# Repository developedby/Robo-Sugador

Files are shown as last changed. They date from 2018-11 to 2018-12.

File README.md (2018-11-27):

# robo-sugador

robo que suga bolinhas de tenis de mesa
Desenvolvido para a disciplina Oficina de Integração 2 - Engenharia de Computação UTFPR-CT - 2018.2

## Autores
* Nicolas Abril
* Álefe Felipe Gonçalves Pereira Dias
* Lucca Rawlyk

## Programas necessários
* O código do robo é feito em python 3 para Raspberry Pi rodando Raspbian
* Os diagramas do HW são em Eagle 9
* Os diagramas do SW são em StarUML
* Os modelos mecânicos e os arquivos para impressão 3D são feitos em SketchUp
* Os diagramas de sistema foram feitos no draw.io
* O aplicativo foi feito com Android Studio

## Bibliotecas necessárias
* RPi.GPIO
* gpiozero
* bluetooth
* bluez (para python3 necessário instalar por pip)
* opencv (talvez seja necessário instalar por pip)

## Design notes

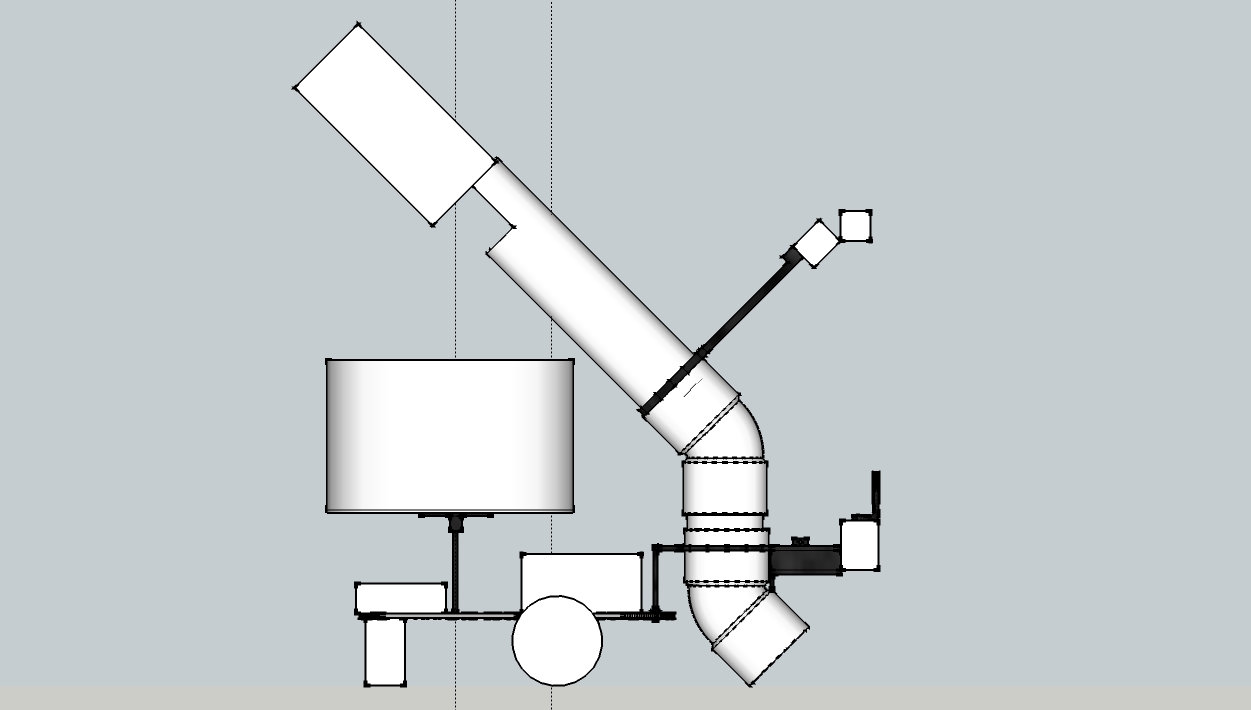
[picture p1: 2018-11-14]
modelagem/mecanica/frontal.jpg

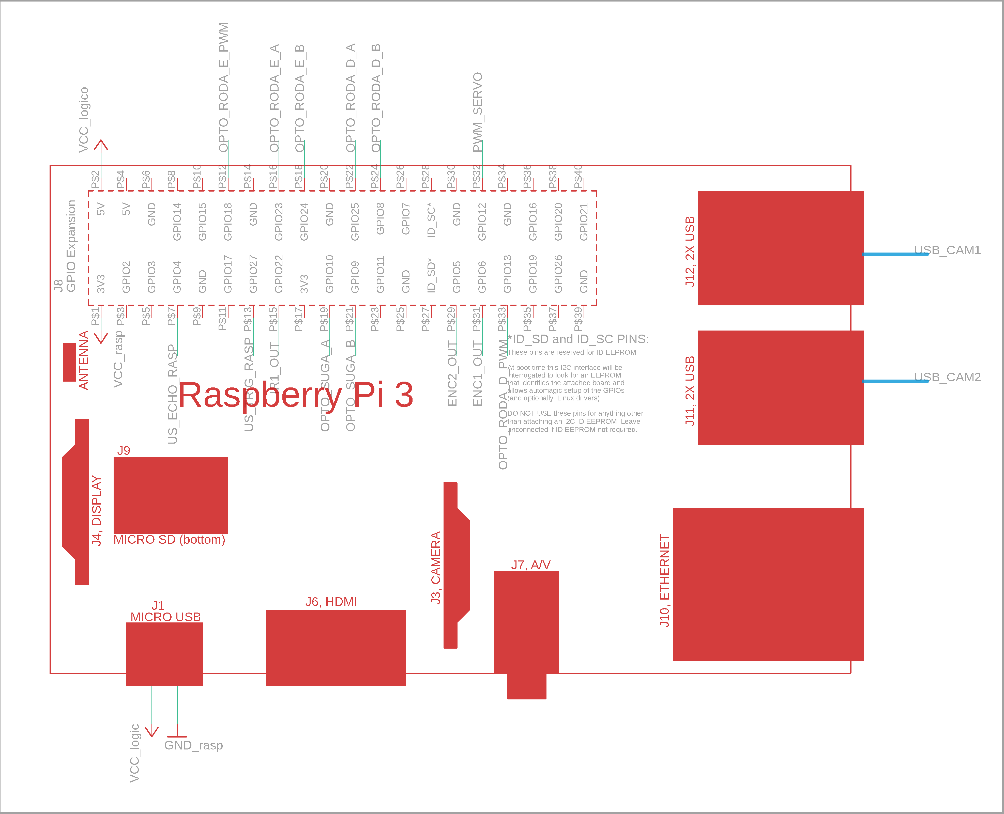
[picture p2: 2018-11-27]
modelagem/hw/esquematico.png

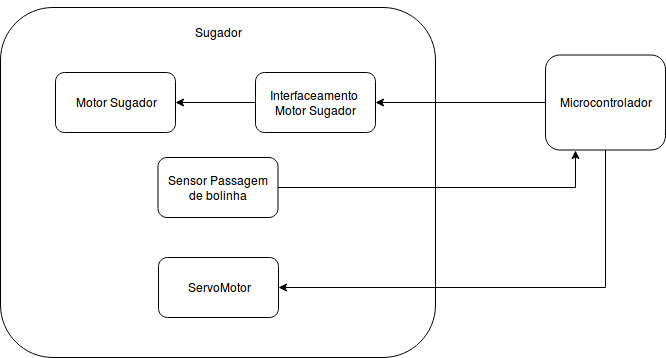
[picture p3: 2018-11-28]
modelagem/sistema/sugador.jpg

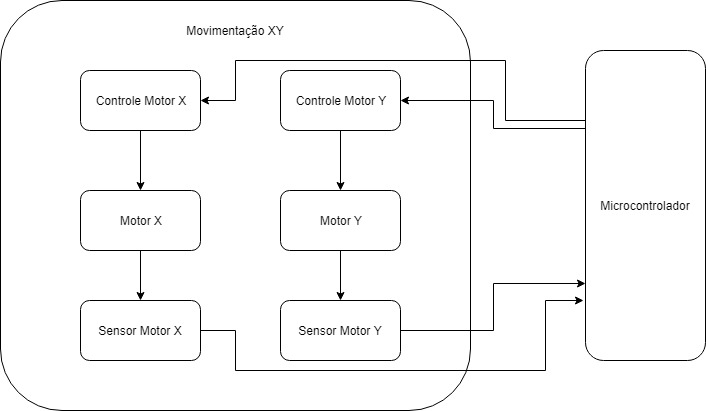
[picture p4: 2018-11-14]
modelagem/sistema/movimentacao XY.jpg

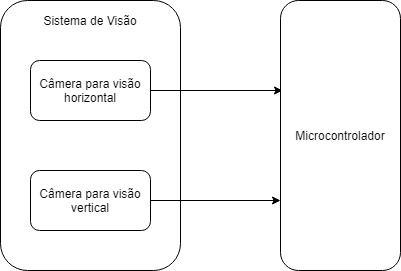
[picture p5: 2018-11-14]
modelagem/sistema/Sistema_visao.jpg

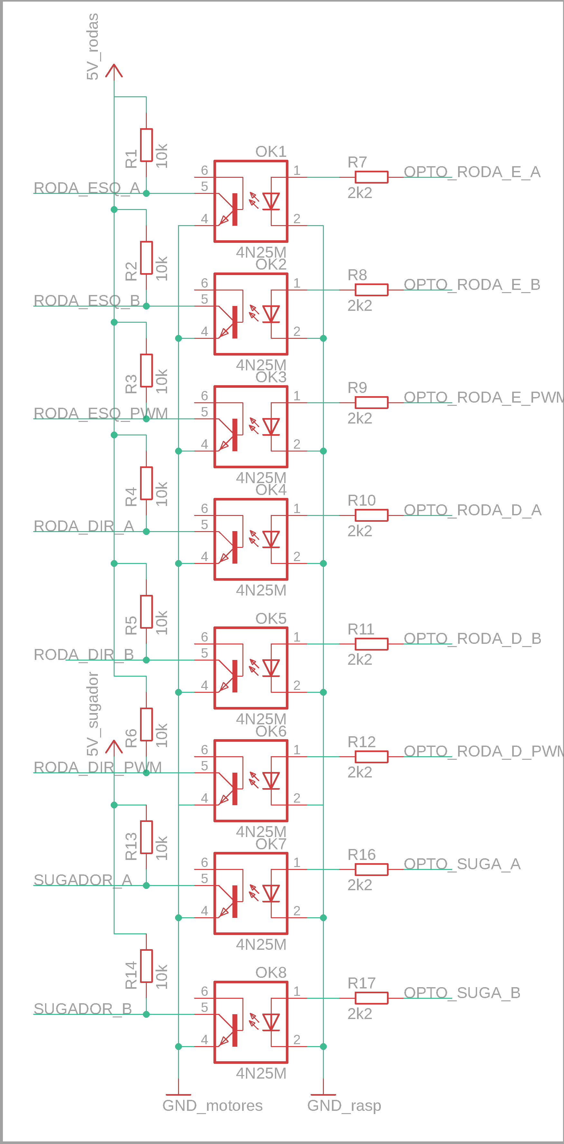
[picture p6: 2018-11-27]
modelagem/hw/esq-opto.png

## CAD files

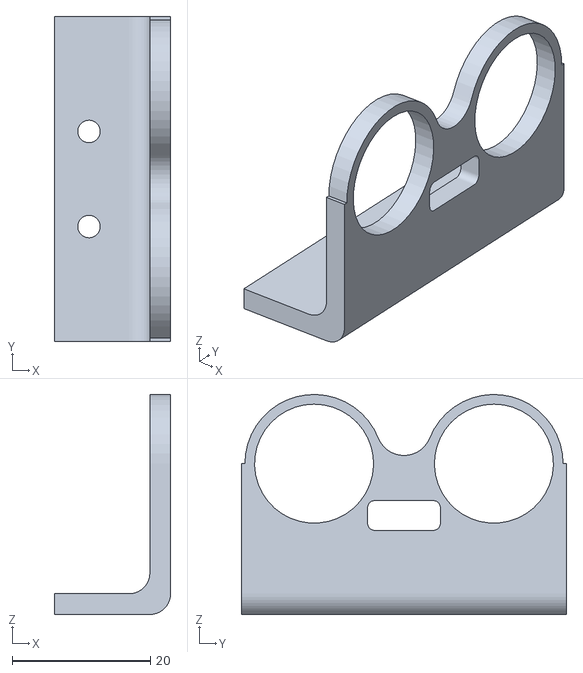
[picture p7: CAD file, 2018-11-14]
modelagem/mecanica/impressao/ultrassom.stl
16.8 x 47.0 x 31.8

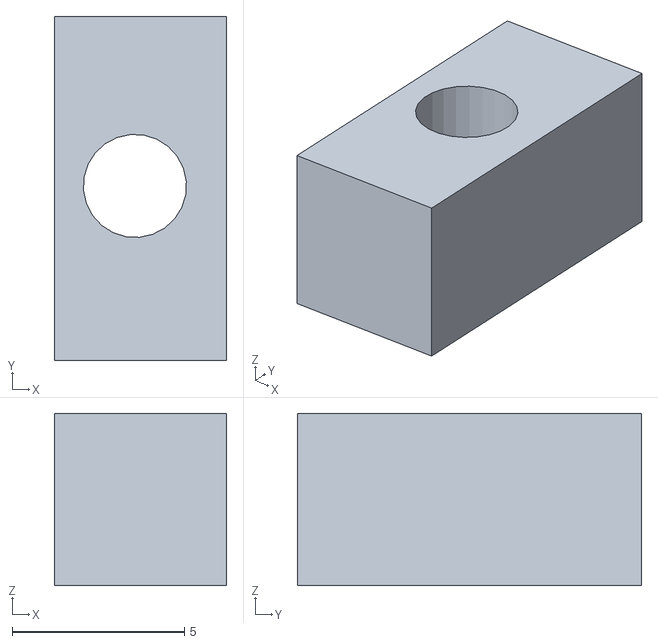
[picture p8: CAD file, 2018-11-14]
modelagem/mecanica/impressao/parafuso.stl
5.00 x 10.0 x 5.00

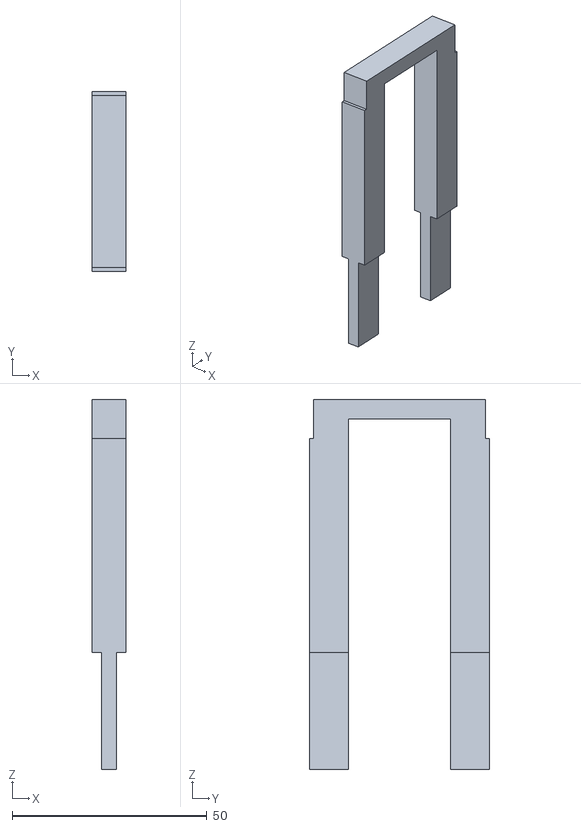
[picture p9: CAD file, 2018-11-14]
modelagem/mecanica/impressao/bacia_carrinho.stl
8.80 x 46.1 x 95.0

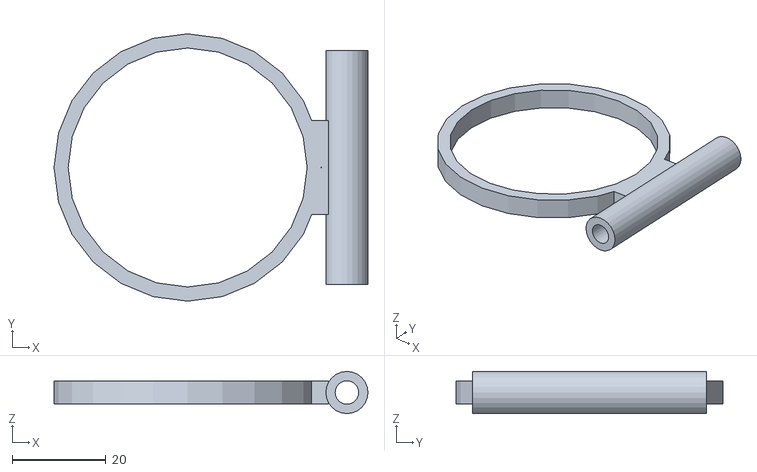
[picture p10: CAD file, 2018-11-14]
modelagem/mecanica/impressao/apoio_cano.stl
67.0 x 57.1 x 9.00

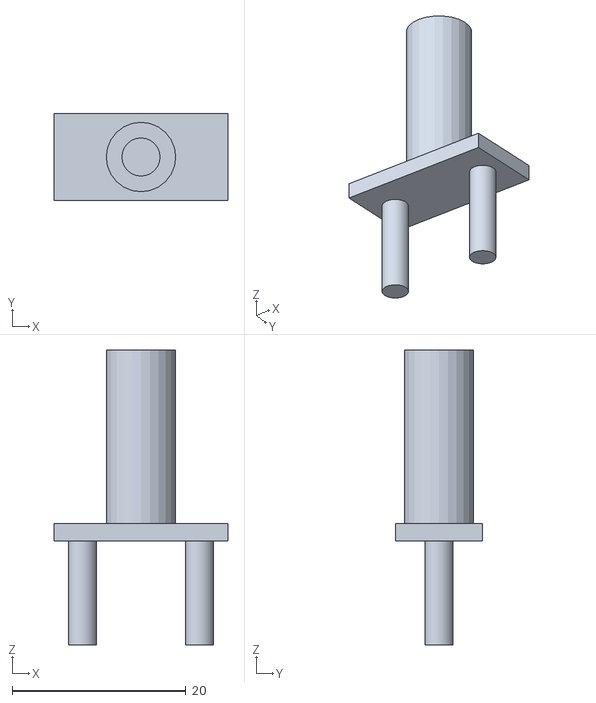
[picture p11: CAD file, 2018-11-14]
modelagem/mecanica/impressao/apoio.stl
20.0 x 10.00 x 34.0

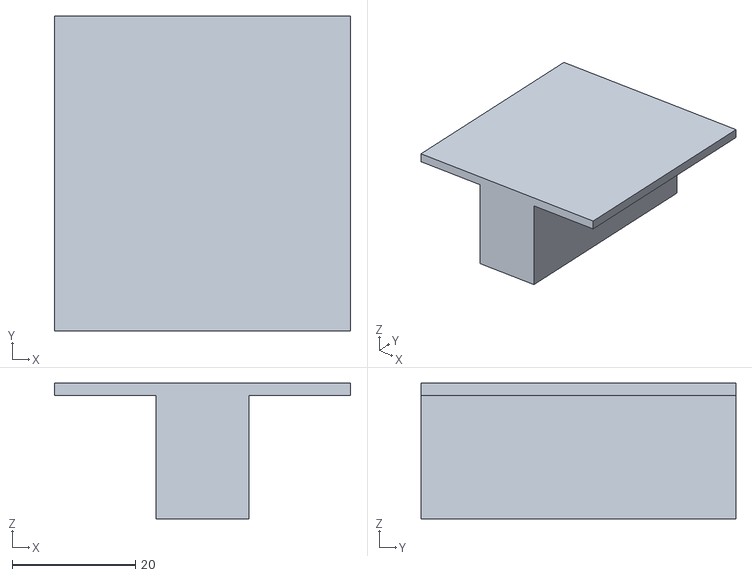
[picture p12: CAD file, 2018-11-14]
modelagem/mecanica/impressao/bacia.stl
48.0 x 51.0 x 22.0

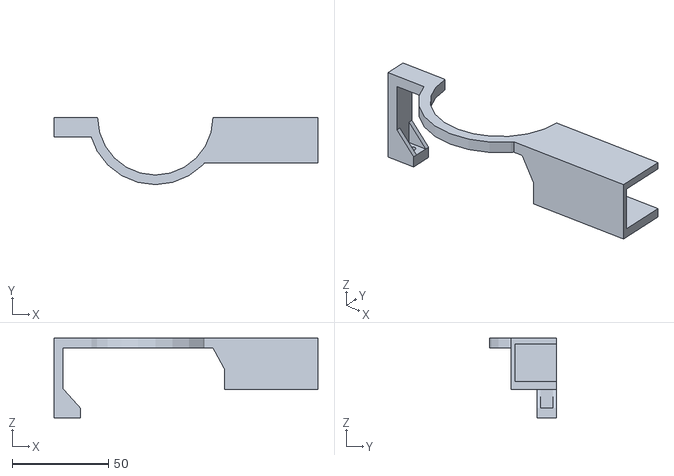
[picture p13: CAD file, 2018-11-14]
modelagem/mecanica/impressao/encaixe_camera_h_a.stl
137.3 x 35.0 x 41.4

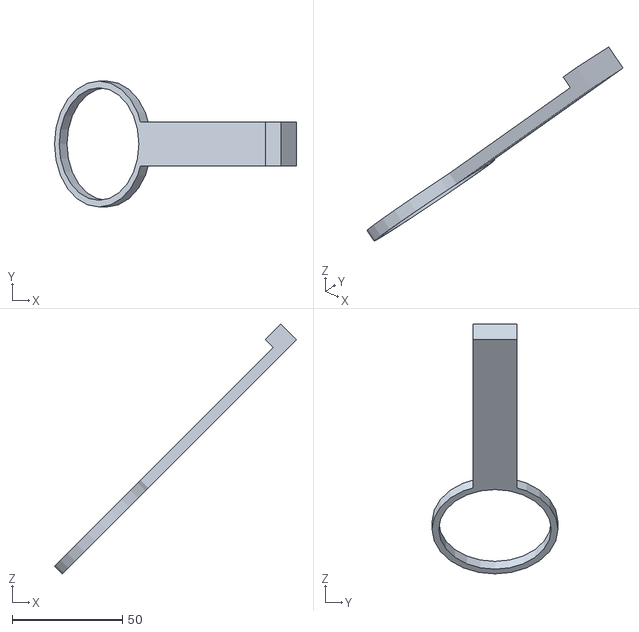
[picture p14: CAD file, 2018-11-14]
modelagem/mecanica/impressao/camera_b.stl
109.6 x 57.1 x 113.1

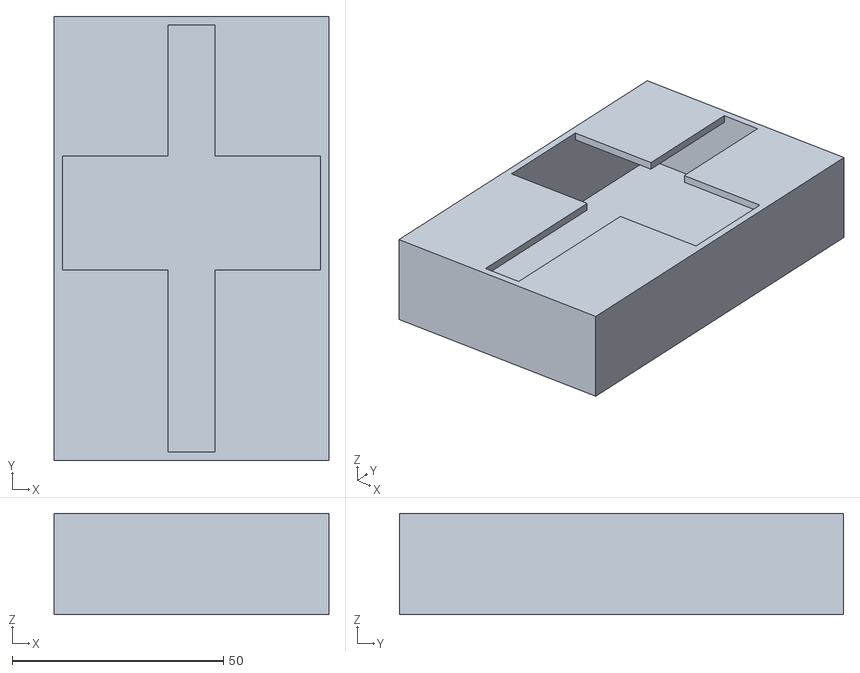
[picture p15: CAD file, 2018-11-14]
modelagem/mecanica/impressao/suporte_hardware.stl
65.0 x 105.0 x 24.0

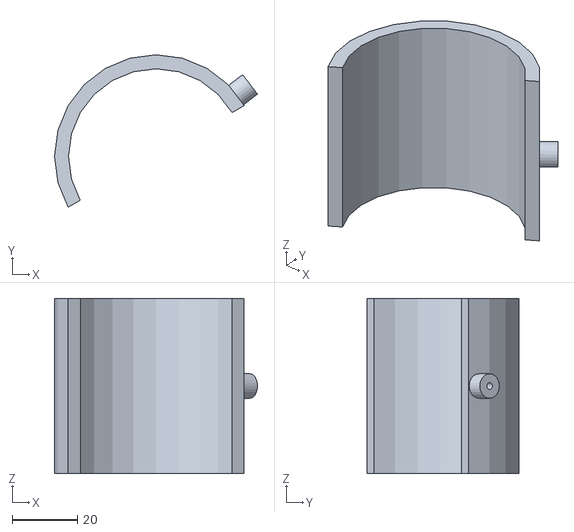
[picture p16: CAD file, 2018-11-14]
modelagem/mecanica/impressao/tampa.stl
62.0 x 46.6 x 53.6

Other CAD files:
modelagem/mecanica/oficina.skp

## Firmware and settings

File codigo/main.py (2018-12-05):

# main.py - Codigo do robo que suga bolinhas
# Informações sobre a licensa no arquivo LICENSE

try:
    import RPi.GPIO as GPIO
except RuntimeError:
    print("Error importing RPi.GPIO!  This is probably because you need superuser privileges.  You can achieve this by using 'sudo' to run your script")
from os.path import realpath


GPIO.setmode(GPIO.BCM)

from robot import Robot

ultrasound_echo_pin = 4
ultrasound_trigger_pin = 27
max_detectable_distance = 1
long_distance_cam_port = (int)(realpath('/dev/v4l/by-id/usb-046d_HD_Pro_Webcam_C920_969829FF-video-index0')[-1])
short_distance_cam_port = (int)(realpath('/dev/v4l/by-id/usb-046d_Camera-video-index0')[-1])
left_wheel_input1_pin = 25
left_wheel_input2_pin = 8
left_wheel_pwm_pin = 13
left_wheel_encoder_pin = 6
left_wheel_encoder_num_holes = 20
right_wheel_input1_pin = 23
right_wheel_input2_pin = 24
right_wheel_pwm_pin = 18
right_wheel_encoder_pin = 5
right_wheel_encoder_num_holes = 20
speed_adjust_delta = 2
infrared_pin = 22
fan_input1_pin = 10
fan_input2_pin = 9
cover_pin = 12
servo_min_angle = 0
servo_max_angle = 180
cover_closed_angle = 40 # Medida mais ou menos certa
cover_open_angle = 10
servo_initial_angle = 22#(cover_closed_angle + cover_open_angle)/2 - Não, tem que iniciar fechado


the_robot = Robot(  # Vision
                    ultrasound_echo_pin,
                    ultrasound_trigger_pin,
                    max_detectable_distance,
                    long_distance_cam_port,
                    short_distance_cam_port,
                    # Mover
                    left_wheel_input1_pin,
                    left_wheel_input2_pin,
                    left_wheel_pwm_pin,
                    left_wheel_encoder_pin,
                    left_wheel_encoder_num_holes,
                    right_wheel_input1_pin,
                    right_wheel_input2_pin,
                    right_wheel_pwm_pin,
                    right_wheel_encoder_pin,
                    right_wheel_encoder_num_holes,
                    speed_adjust_delta,
                    # Sucker
                    infrared_pin,
                    fan_input1_pin,
                    fan_input2_pin,
                    cover_pin,
                    servo_initial_angle,
                    servo_min_angle,
                    servo_max_angle,
                    cover_closed_angle,
                    cover_open_angle)
the_robot.intelligence.mainLoop()

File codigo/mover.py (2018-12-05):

# mover.py - o movimentador do robo, cuida de andar pra frente, para tras e para os lados

from wheel import Wheel
from threading import Timer
import os

def clamp(num, min_value, max_value):
   return max(min(num, max_value), min_value)

class Mover():
    speed_adjust_frequency = 0.2
    wheel_initial_forward_speed = (0, 0)
    wheel_initial_turn_speed = 80

    def __init__ (self, input1_a_pin, input2_a_pin, pwm_a_pin, encoder_a_pin, num_a_holes, input1_b_pin, input2_b_pin, pwm_b_pin, encoder_b_pin, num_b_holes, speed_adjust_delta):
        self.left_wheel = Wheel(input1_a_pin, input2_a_pin, pwm_a_pin, encoder_a_pin, num_a_holes, .9*self.speed_adjust_frequency)
        self.right_wheel = Wheel(input1_b_pin, input2_b_pin, pwm_b_pin, encoder_b_pin, num_b_holes, .9*self.speed_adjust_frequency)
        self.left_wheel_abs_sent_speed = None               # velocidade enviada a roda, em % do pwm
        self.right_wheel_abs_sent_speed = None
        self.left_wheel_required_speed = None           # velocidade desejada, em graus por segundo
        self.right_wheel_required_speed = None
        self.speed_adjust_delta = speed_adjust_delta    # quanto a velocidade enviada varia a cada ajuste
        self.speed_adjust_timer = None
        self.moving = False


    def adjustSpeed(self):
        if self.sign(self.left_wheel_required_speed) == self.sign(self.right_wheel_required_speed):
            if self.left_wheel_required_speed > 0:
                self.wheel_initial_forward_speed = (self.left_wheel_abs_sent_speed, self.right_wheel_abs_sent_speed)
            else:
                self.wheel_initial_forward_speed = (self.right_wheel_abs_sent_speed, self.left_wheel_abs_sent_speed)

        if self.left_wheel.encoder.angular_velocity > abs(self.left_wheel_required_speed):
            self.left_wheel_abs_sent_speed -= self.speed_adjust_delta
        elif self.left_wheel.encoder.angular_velocity < abs(self.left_wheel_required_speed):
            self.left_wheel_abs_sent_speed += self.speed_adjust_delta

        if self.right_wheel.encoder.angular_velocity > abs(self.right_wheel_required_speed):
            self.right_wheel_abs_sent_speed -= self.speed_adjust_delta
        elif self.right_wheel.encoder.angular_velocity < abs(self.right_wheel_required_speed):
            self.right_wheel_abs_sent_speed += self.speed_adjust_delta

        self.left_wheel_abs_sent_speed = clamp(self.left_wheel_abs_sent_speed, 0, 99)
        self.right_wheel_abs_sent_speed = clamp(self.right_wheel_abs_sent_speed, 0, 99)
        self.left_wheel.spin(self.sign(self.left_wheel_required_speed)*self.left_wheel_abs_sent_speed)
        self.right_wheel.spin(self.sign(self.right_wheel_required_speed)*self.right_wheel_abs_sent_speed)

        print("Vel desejada roda direita:", self.right_wheel_required_speed)
        print("Vel lida na roda direita:", self.sign(self.right_wheel_required_speed) * self.right_wheel.encoder.angular_velocity)
        print("Escrevendo roda direita:", self.sign(self.right_wheel_required_speed)*self.right_wheel_abs_sent_speed)

        print("Vel desejada roda esquerda:", self.left_wheel_required_speed)
        print("Vel lida na roda esquerda:", self.sign(self.left_wheel_required_speed) * self.left_wheel.encoder.angular_velocity)
        print("Escrevendo roda esquerda:", self.sign(self.left_wheel_required_speed)*self.left_wheel_abs_sent_speed)

        self.setTimer()

    def moveForward(self, speed):
        if speed > 0:
            self.left_wheel_abs_sent_speed = self.wheel_initial_forward_speed[0]
            self.right_wheel_abs_sent_speed = self.wheel_initial_forward_speed[1]
        else:
            self.left_wheel_abs_sent_speed = self.wheel_initial_forward_speed[1]
            self.right_wheel_abs_sent_speed = self.wheel_initial_forward_speed[0]

        self.left_wheel_required_speed = speed
        self.right_wheel_required_speed = speed
        self.left_wheel.spin(self.left_wheel_abs_sent_speed)
        self.right_wheel.spin(self.right_wheel_abs_sent_speed)

        print("Andando pra frente com vel", speed)

        if not self.speed_adjust_timer or not self.speed_adjust_timer.is_alive():
            self.setTimer()

    def turn(self, speed): # usando sentido positivo: antihorario
        self.left_wheel_required_speed = -speed
        self.right_wheel_required_speed = speed
        self.left_wheel_abs_sent_speed = self.wheel_initial_turn_speed
        self.right_wheel_abs_sent_speed = self.wheel_initial_turn_speed

        print("Girando com vel", speed)

        if not self.speed_adjust_timer or not self.speed_adjust_timer.is_alive():
            self.setTimer()

    def stop(self):
        self.stopTimer()
        self.left_wheel.spin(0)
        self.right_wheel.spin(0)
        self.left_wheel_abs_sent_speed = 0
        self.right_wheel_abs_sent_speed = 0
        self.left_wheel_required_speed = 0
        self.right_wheel_required_speed = 0
        print("Parando rodas")

    def stopTimer(self):
        if self.speed_adjust_timer:
            self.speed_adjust_timer.cancel()
            self.speed_adjust_timer = None

    def setTimer(self):
        self.speed_adjust_timer = Timer(self.speed_adjust_frequency, self.adjustSpeed)
        try:
            self.speed_adjust_timer.start()
        except:
            os.system('systemctl reboot')
        #print('ativando timer das rodas com tempo', self.speed_adjust_frequency)


    def sign(self, x):
        if x == 0:
            return 0
        elif x > 0:
            return 1
        else:
            return -1

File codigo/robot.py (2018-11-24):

# robot.py - Representa o robo como um todo. So criar e ele ja funciona


from vision import Vision
from mover import Mover
from sucker import Sucker
from communicator import Communicator

class Robot :
    def __init__ (self,
                    # Vision
                  ultrasound_echo_pin,
                  ultrasound_trigger_pin,
                  max_detectable_distance,
                  long_distance_cam_port,
                  short_distance_cam_port,
                    # Mover
                  left_wheel_input1_pin,
                  left_wheel_input2_pin,
                  left_wheel_pwm_pin,
                  left_wheel_encoder_pin,
                  left_wheel_encoder_num_holes,
                  right_wheel_input1_pin,
                  right_wheel_input2_pin,
                  right_wheel_pwm_pin,
                  right_wheel_encoder_pin,
                  right_wheel_encoder_num_holes,
                  speed_adjust_delta,
                    # Sucker
                  infrared_pin,
                  fan_input1_pin,
                  fan_input2_pin,
                  cover_pin,
                  servo_initial_angle,
                  servo_min_angle,
                  servo_max_angle,
                  cover_closed_angle,
                  cover_open_angle):
        self.vision = Vision(ultrasound_echo_pin,
                             ultrasound_trigger_pin,
                             max_detectable_distance,
                             long_distance_cam_port,
                             short_distance_cam_port)
        self.mover = Mover(left_wheel_input1_pin,
                           left_wheel_input2_pin,
                           left_wheel_pwm_pin,
                           left_wheel_encoder_pin,
                           left_wheel_encoder_num_holes,
                           right_wheel_input1_pin,
                           right_wheel_input2_pin,
                           right_wheel_pwm_pin,
                           right_wheel_encoder_pin,
                           right_wheel_encoder_num_holes,
                           speed_adjust_delta)
        self.sucker = Sucker(infrared_pin,
                             fan_input1_pin,
                             fan_input2_pin,
                             cover_pin,
                             servo_initial_angle,
                             servo_min_angle,
                             servo_max_angle,
                             cover_closed_angle,
                             cover_open_angle)
        self.communicator = Communicator()
        self.intelligence = Intelligence(self)

from intelligence import Intelligence

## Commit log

2018-11-07 Comeca encoder
2018-11-12 Adiciona dependencias de biblioteca
2018-11-12 Faz classe camera e comeca ultrassom, falta terminar __init__
2018-11-13 Inicia classe wheel
2018-11-13 Conserta wheel, faz dcmotor
2018-11-13 faz classe Fan
2018-11-13 Corrige infrared, implementa servo com gpiozero
    [servo_motor.py]
2018-11-14 Corrige e melhora os modulos, cria robot.py
    [cover.py, dc_motor.py, encoder.py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]
2018-11-14 Corrige bluetooth (comunicador) e infrared
    [communicator.py, robot.py]
2018-11-14 Corrige robot para communicator e cria robot na main
    [main.py, robot.py]
2018-11-14 Inclui parametros self que faltavam, corrige erros de indentacao
    [camera.py, communicator.py, cover.py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]
2018-11-14 corrige mais selfs e tabs
    [communicator.py, servo_motor.py]
2018-11-14 Corrige bugs de digitacao
    [mover.py, robot.py, ultrasound.py]
2018-11-14 Cria sugador, corrige tampa e mais algo que nao lembro
    [communicator.py, cover.py, robot.py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]
2018-11-14 um mointao de coisas
2018-11-14 Adiciona modelagem do hardware
    [robo_sugador.sch]
2018-11-14 adiciona modelagem mecanica e do sistema]
    [apoio.stl, apoio_cano.stl, bacia.stl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]
2018-11-15 muda nome da funcao acha raquete, faz funcao que pega distancia do obstaculo
2018-11-15 mapeia gpios, passa numero das portas para o robo, faz estado no sugador
2018-11-15 faz rascunho de inteligencia
2018-11-16 Coloca limite na velocidade atual das rodas
2018-11-16 Testa alguns metodos diferentes de detectar bolinhas'
2018-11-17 Um monte de coisa
2018-11-18 passa mapeamento de gpio para a main
2018-11-19 Adiciona modo voltar pra casa
2018-11-19 corrige erros de sintaxe
    [communicator.py, intelligence.py]
2018-11-19 corrige porta do socket
    [main.py]
2018-11-19 Corrige bugs, agora roda
    [camera.py, communicator.py, cover.py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]
2018-11-19 Corrige bluetooth, tem ruim com a camera ruim
    [communicator.py, teste_imagem1.py]
2018-11-20 Corrige alguns erros para que o programa rode em todos os modos sem quebrar, mas ainda ha bugs
    [cover.py, encoder.py, intelligence.py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]
2018-11-20 arruma mais algumas coisas, muda comparacao de [0][0][0]
2018-11-20 motores, movimentacao, infravermelho, encoder e ultrassom testados, apenas o infravermelho funciona
2018-11-20 arruma servo motor, e ultrassom nao funciona
2018-11-21 faz botao que troca pro modo manual
2018-11-23 tenta usar resistores no lugar do conversor logico e aumentar o tempo do trig
2018-11-23 Resolve problema mecanico do Cover, ajusta angulos
    [main.py]
2018-11-24 muda forma de ler velocidade das rodas
2018-11-26 Solta o motor e da sleep no modo sleep
2018-11-26 faz ele parar de girar pra sempre
2018-11-27 Deleta arquivos lixos de backup
2018-11-27 Atualiza esquematico de hw e suas figuras
    [robo_sugador.sch]
2018-12-03 reinicia OS quando da erro de thread
2018-12-03 Ajusta constante de visao e faz sugador sugar por periodo
2018-12-03 Nao lembro o que faz
2018-12-05 Corrige nome de variaveis e muda speed_adjust_delta
    [main.py, mover.py]
2018-12-05 Faz robo parar de andar no sentido errado
2018-12-05 manda imprimir velocidade
2018-12-05 manda imprimir velocidade direito
2018-12-05 corrige logica velocidades
2018-12-05 corrige logica velocidades de novo e atualiza vel mais devagar
    [main.py, mover.py]
